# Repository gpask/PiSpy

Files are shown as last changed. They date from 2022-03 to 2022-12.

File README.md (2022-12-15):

# PiSpy: An Affordable, Accessible, and Flexible Imaging Platform for the Automated Observation of Organismal Biology and Behavior

<p align="center">
  
</p>

PiSpy has now been published at PLOS One! Check it out [here](https://journals.plos.org/plosone/article?id=10.1371/journal.pone.0276652)\!

This project is licensed under [GNU General Public License v3.0](https://github.com/gpask/PiSpy/blob/master/LICENSE)\
The hardware is licensed under [CERN-OHL-S v2](https://github.com/gpask/PiSpy/blob/master/Hardware/LICENSE)\

<br /><span xmlns:dct="http://purl.org/dc/terms/" property="dct:title">PiSpy</span> by <span xmlns:cc="http://creativecommons.org/ns#" property="cc:attributionName">Benjamin I. Morris, Marcy J. Kittredge, Bea Casey, Owen Meng, André Maia Chagas, Matt Lamparter, Thomas Thul, Gregory M. Pask</span> is licensed under a <a rel="license" href="http://creativecommons.org/licenses/by-sa/4.0/">Creative Commons Attribution-ShareAlike 4.0 International License</a>.<br /></a>

oshw_facts (1)

PiSpy OSHWA\
This project is Open Source Hardware Association certified [OSHWA UID US002095](https://certification.oshwa.org/us002095.html)

**Contents:**
* [Summary](#summary)
* [Overview of the PiSpy](#overview-of-the-pispy)
* [Video and time lapse image recording across various scales](#video-and-time-lapse-image-recording-across-various-scales)
* [Custom setup for monitoring ant behavior](#custom-setup-for-monitoring-ant-behavior)

## Summary
A great deal of understanding can be gleaned from direct observation of
organismal growth, development, and behavior. However, direct
observation can be time consuming and influence the organism through
unintentional stimuli. Additionally, video capturing equipment can often
be prohibitively expensive, difficult to modify to one's specific needs,
and may come with unnecessary features. Here, we describe the PiSpy, a
low-cost, automated video acquisition platform that uses a Raspberry Pi
computer and camera to record video or images at specified time
intervals or when externally triggered. All settings and controls, such
as programmable light cycling, are accessible to users with no
programming experience through an easy-to-use graphical user.
Importantly, the entire PiSpy system can be assembled for less than
\$100 using laser-cut and 3D-printed components. We demonstrate the
broad applications and flexibility of the PiSpy across a range of model
and non-model organisms. Designs, instructions, and code can be accessed
through an online repository, where a global community of PiSpy users
can also contribute their own unique customizations and help grow the
community of open-source research solutions.

## Overview of the PiSpy

<p align="center">
  
</p>
Shown above is the base model of the PiSpy for simple image or video
capture (Fig. 1a). A 3D printable holder mounts both the Raspberry Pi
and PiCamera to a laser cut wooden frame, allowing for easy height
adjustment (Fig. 1A-B). The stands on the frame are also reversible, and
a 3D-printed ball and socket mounts the PiCamera, allowing for free
rotation (Fig. 1C). Optionally, the Raspberry Pi computer can connect to
input and/or output components, such as a motion sensor or lighting,
respectively. This entire setup can be assembled for less than \$100, or
cheaper if multiple setups are being bought at once or certain features
are omitted (see Bill of Materials in GitHub. A complete user's guide
and assembly manual can be found in the Supplementary Materials of the
published paper and will also be continually updated on the GitHub
repository (https://github.com/gpask/PiSpy). The GUI for the PiSpy,
written in Python3 using the TKinter package, controls the functionality
of the PiSpy. Features include capture mode, timed or input-triggered
capture, light control, and camera resolution (Fig. 1D). For more
advanced controls, such as changing the default image/video name and
storage location or the specific camera settings, instructions are
written in the user's manual for how to edit these in the code itself.

## Video and time lapse image recording across various scales

Imaging of 10 *D. melanogaster* larval locomotion on an agar plate
provided sufficient resolution for analysis with the ImageJ image
processing software, as shown in the above video (sped up to 5x speed):
<p align="center">
  Fig. 2a
</p>

Video of crayfish behavior when placed in an aquarium allowed for the
observation of subtle movements of the swimmerets and legs, even though
the animals were underwater and being viewed through a plastic
container:
<p align="center">
  Fig. 2b
</p>

Automated image capture also makes the PiSpy an effective device for
capturing and visualizing organismal growth over time. Time-lapse
imaging every 5 minutes (and converted to a video at 225 fps) of various beans (*Phaseolus vulgaris*) growing in clear
planters showed detailed root and shoot growth:
<p align="center">
  Fig. 2c
</p>

At a smaller scale, imaging every 5 minutes (and converted to a video at 90 fps of the soil bacterium *Bacillus mycoides*
captured the growth and expansion process over time:
<p align="center">
  Fig. 2c
</p>

## Custom setup for monitoring ant behavior

<p align="center">
  Fig. 3a
</p>

The flexibility of the PiSpy allows it to be customized for more
specific research purposes, as shown above. For example, we have used the PiSpy to
monitor the social behaviors in colonies of the Indian jumping ant,
*Harpegnathos saltator*. Because the ants are housed in nestboxes of a
fixed size, we have modified the wooden frame and mount to enclose the
container to allow for easy overhead recording of the colony, as shown in the image above.
To maintain a light-dark cycle for the ants, we used the LED light
control capabilities of the PiSpy to be able to record social behaviors
throughout the day. Custom LED printed circuit boards (PCBs) can be
connected to the general-purpose input output (GPIO) pin of the
Raspberry Pi and allow for the cycling of white and red lighting.

The sample videos below show the ability of the PiSpy to record animal behavior
in both day and night, with sufficient resolution to capture specific behaviors 
such as antennal dueling (asseen in the daytime recording).
In our experiment, the red light is not detected by the ants but allows
for both day and night imaging. Specific camera settings are used to
record in each different lighting conditions to ensure the desirable
imaging quality. We have programmed in default camera settings for day
and night recording, but the user's manual provides instructions for how
to modify these within the PiSpy code.
<p align="center">
  Fig. 3b
</p>
<p align="center">
  Fig. 3c
</p>

The GPIO pins of the Raspberry Pi can also be used to trigger image or
video capture with an external sensor, such as a motion sensor or IR
break beam. In our setup (below), an ant disrupts the IR beam as it walks to a
foraging arena, and again when it returns to the main colony. The physical setup is 
shown in the image below, including the LEGO contraption to holding the break beam (right side):
<p align="center">
  Fig. 3b
</p>

A sample video in which ants return to the main colony carrying crickets is shown below:
<p align="center">
  Fig. 3c
</p>

As an alternative to automated recordings at fixed time intervals, triggered recordings such as these
could be used to monitor specific activities, such as feeding patterns
or other behaviors. It is our hope that users will create their own
modifications of the PiSpy hardware and/or software and will share these
for use by other researchers and inspire further customizations,
allowing it to serve as both a general use tool and one that can be
applied to highly specific experimental approaches.

Contributors to PiSpy:
Benjamin I. Morris, Marcy J. Kittredge, Bea Casey, Owen Meng, André Maia Chagas, Matt Lamparter, Thomas Thul, Gregory M. Pask

For this README, all videos were converted to GIF using ezgif.com

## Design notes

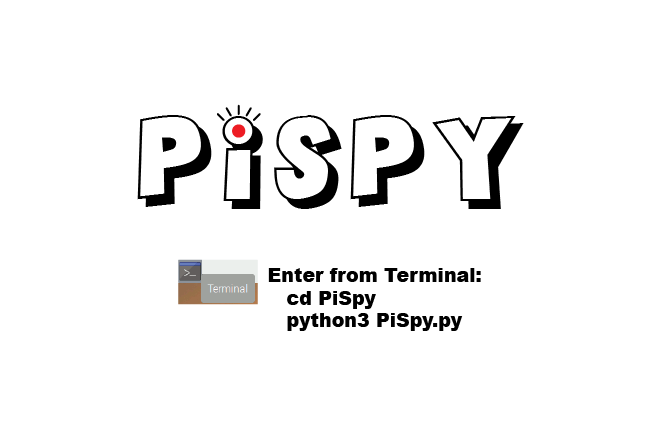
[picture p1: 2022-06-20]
PiSpy desktop.png

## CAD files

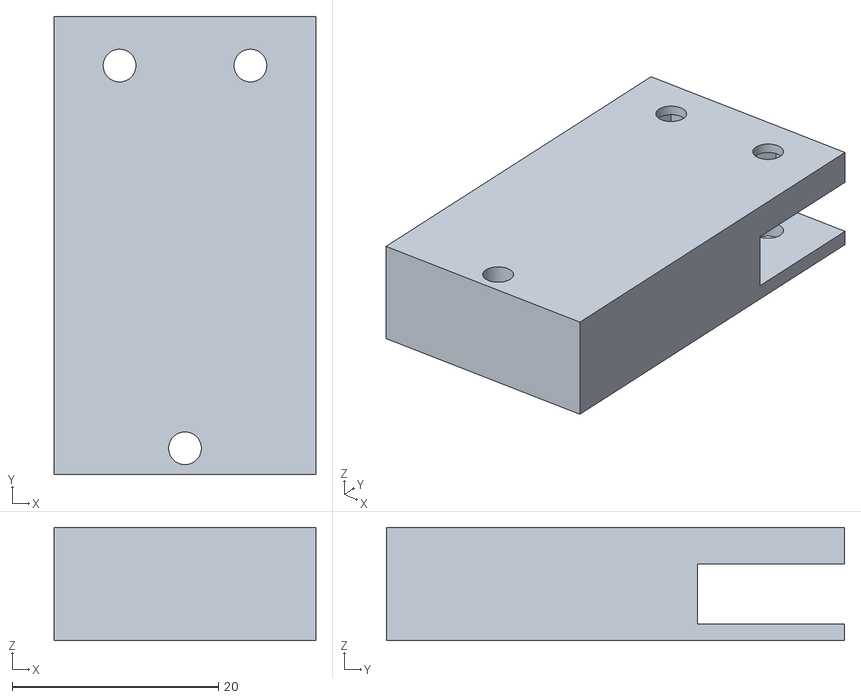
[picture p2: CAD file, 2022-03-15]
Hardware/LED light setup/3D printing/slider mounting bracket.STL
25.4 x 44.4 x 11.0

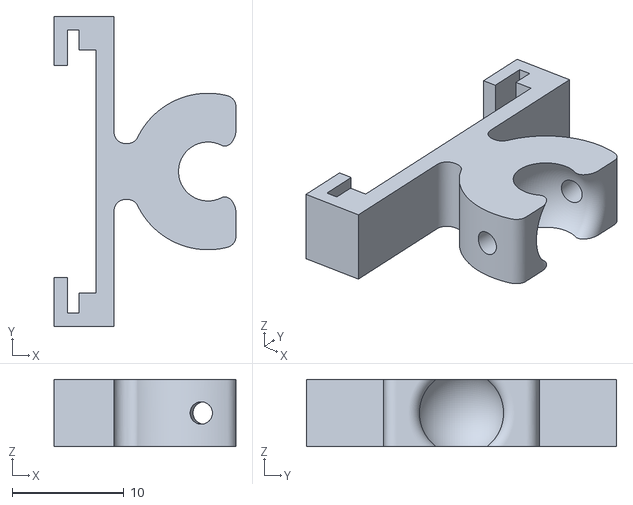
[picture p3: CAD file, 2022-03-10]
Hardware/Original PiSpy/Camera mount.stl
16.3 x 27.7 x 6.00

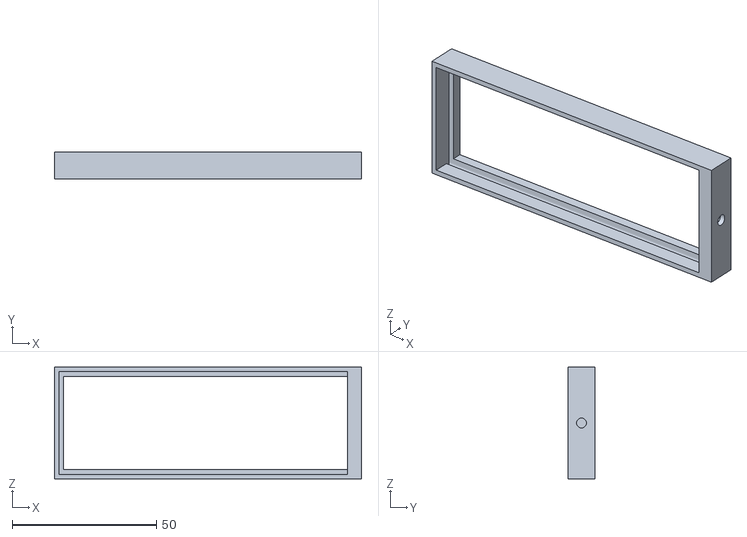
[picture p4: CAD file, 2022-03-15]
Hardware/LED light setup/3D printing/light slider.STL
106.4 x 9.53 x 38.7

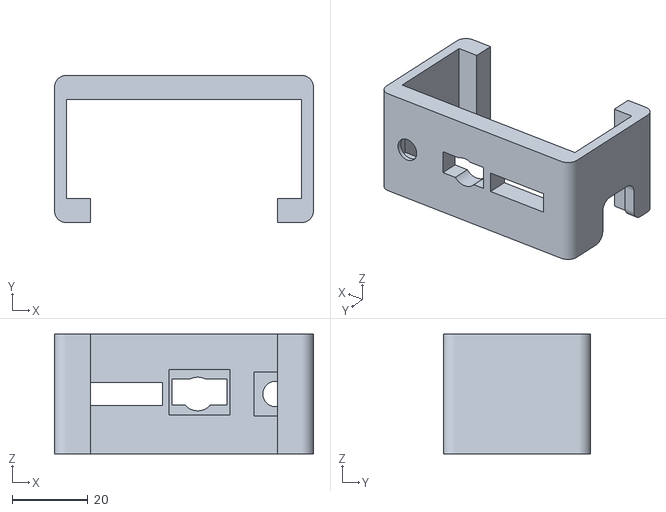
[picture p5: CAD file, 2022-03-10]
Hardware/Original PiSpy/RPi mount.STL
68.6 x 39.0 x 31.8

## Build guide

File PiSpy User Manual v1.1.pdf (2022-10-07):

PiSpy User’s Manual | 1

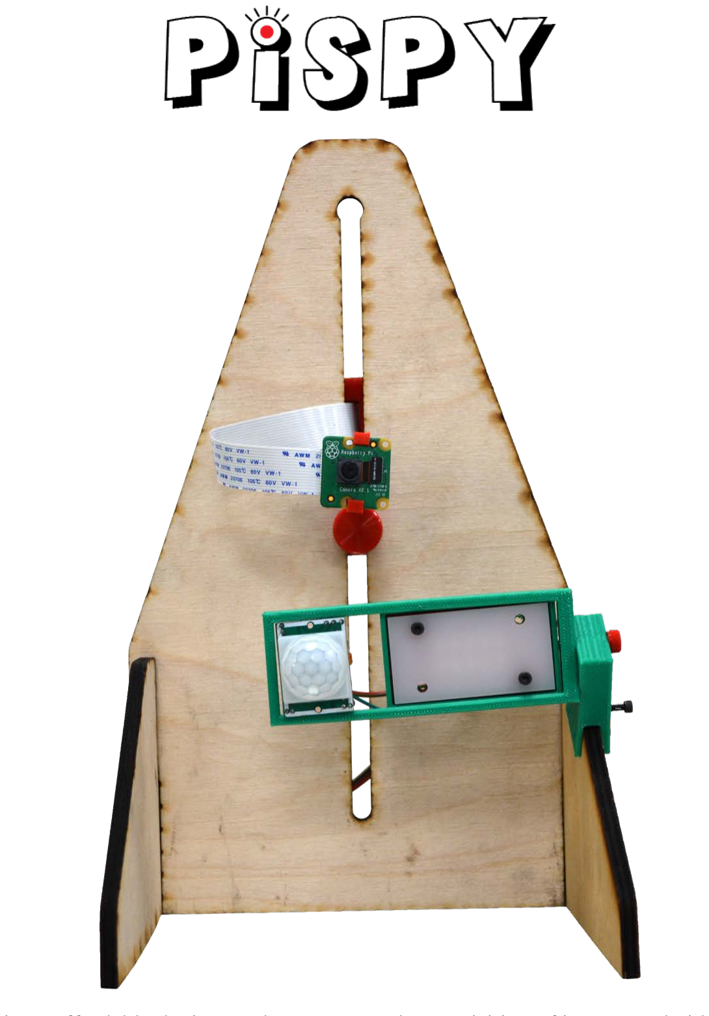
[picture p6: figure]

The PiSpy is an affordable device used to automate the acquisition of images and videos. It was shared on bioRxiv in 2022 (https://www.biorxiv.org/content/10.1101/2022.03.21.485129v1). It uses a Raspberry Pi computer and camera to record video and images at specified time intervals or when triggered by an input signal, such as a motion sensor or force plate. Additionally, it can automate the control of LED lights. All settings for the PiSpy are controlled through a graphical user interface that uses the TKinter Python package. The following user guide will outline how to set up and operate the PiSpy. Our testing was with a Raspberry Pi3b or Pi4, which is primarily what this guide is written for, but with some modifications the PiSpy can also be used with older Raspberry Pi models.

### Table of Contents

PiSpy Hardware Assembly

Fabrication of Components

The hardware files associated with PiSpy can be downloaded from the GitHub repository (https://github.com/gpask/PiSpy/tree/master/Hardware/Original%20PiSpy).

The wooden stand used to mount PiSpy can be laser cut from 3/8 inch plywood using the .svg file. The 3D-printed components were printed with polylactic acid (PLA) using the .stl files.

Assembly Instructions

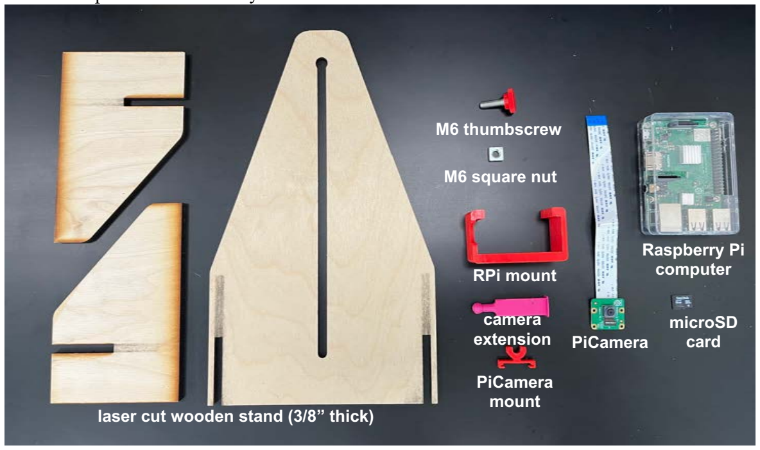
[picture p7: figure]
laser cut wooden stand (3/8” thick); PiCamera mount; camera extension; RPi mount; M6 square nut; M6 thumbscrew; PiCamera; microSD card; Raspberry Pi computer

All the components for assembly are shown below:

First, assemble the wooden stand by sliding each support into the taller mount like so:

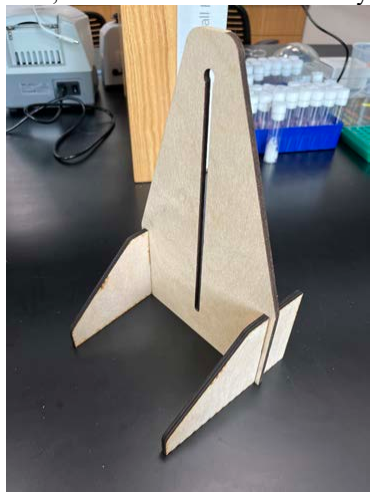
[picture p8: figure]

Next, detach the ribbon cable from the PiCamera and insert one end into the Raspberry Pi’s camera port.

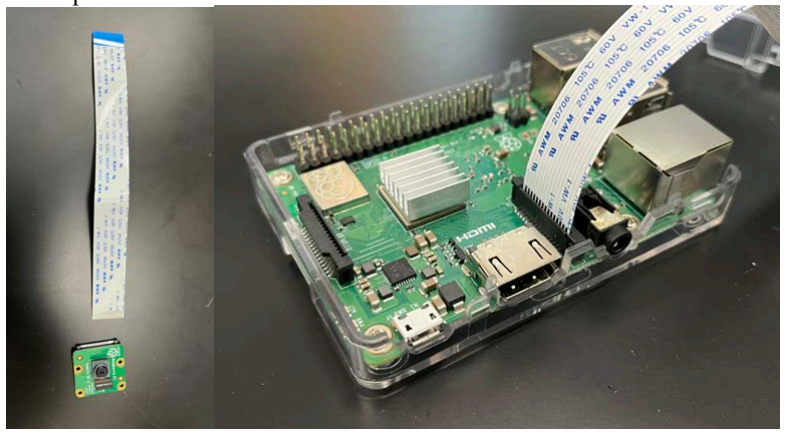
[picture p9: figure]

Then insert the PiCamera into the PiCamera mount (be sure not to block the ribbon cable connector).

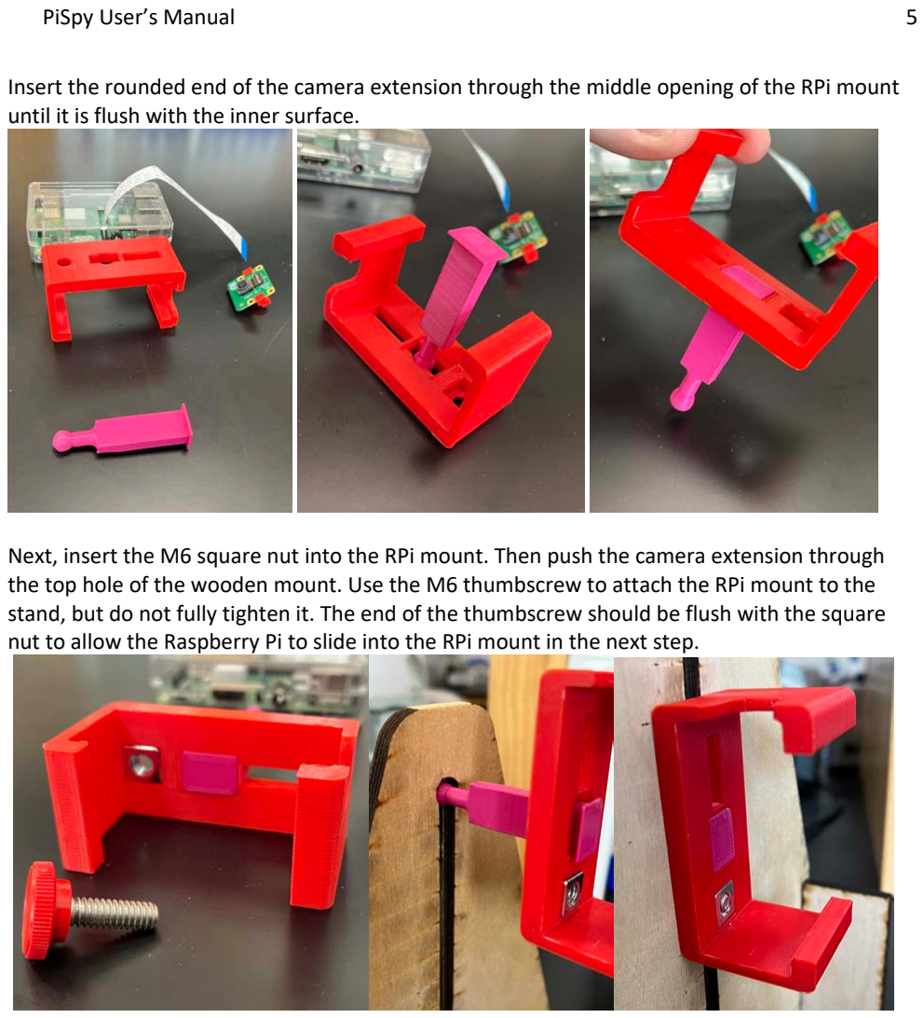
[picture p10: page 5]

Insert the rounded end of the camera extension through the middle opening of the RPi mount until it is flush with the inner surface.

Next, insert the M6 square nut into the RPi mount. Then push the camera extension through the top hole of the wooden mount. Use the M6 thumbscrew to attach the RPi mount to the stand, but do not fully tighten it. The end of the thumbscrew should be flush with the square nut to allow the Raspberry Pi to slide into the RPi mount in the next step.

First insert the camera ribbon cable through the top rectangular opening in the RPi mount. Then slide the Raspberry Pi and case into the RPi mount. (Note: If your specific case does not fit inside RPi mount, you can adjust the scale of that specific axis before 3D printing.)

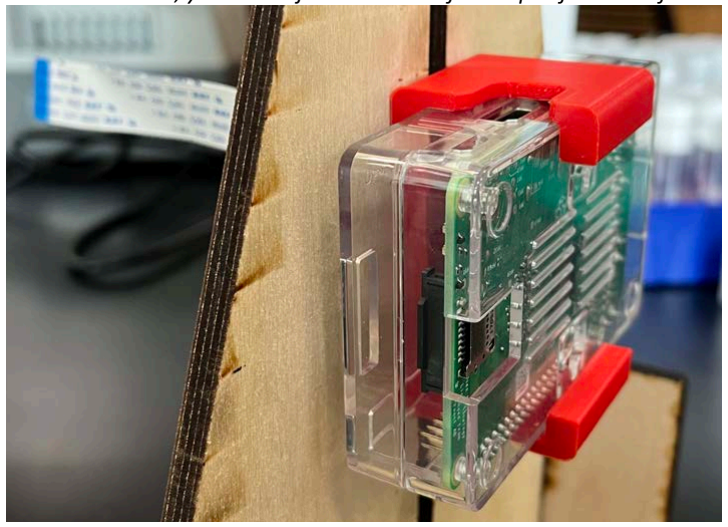
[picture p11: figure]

Attach the PiCamera and mount to the “ball” end of the camera extension and connect the ribbon cable.

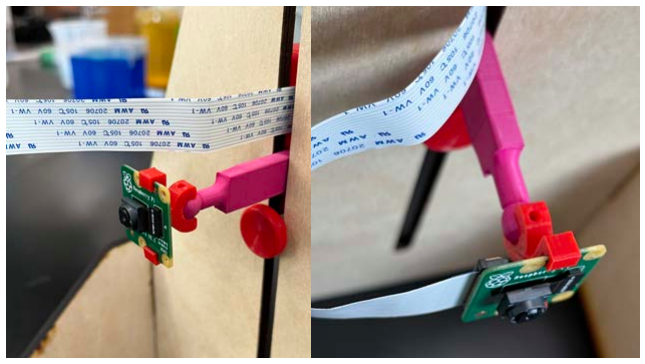
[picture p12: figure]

Connect the power supply, HDMI cable, keyboard, and mouse. The microSD card will be used in the next section to load the PiSpy disk image and will be inserted as shown below:

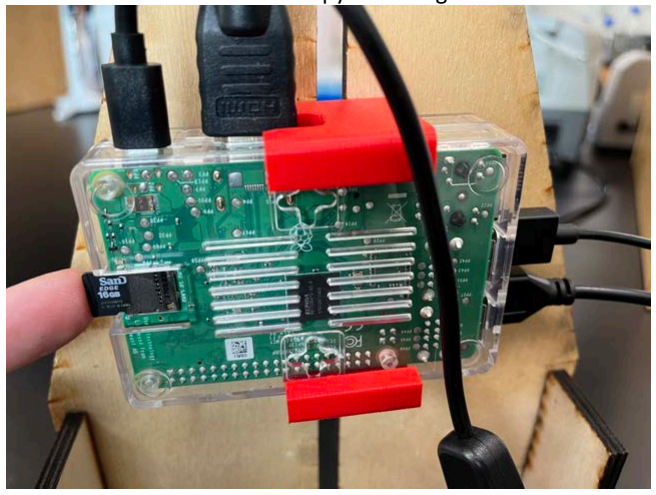
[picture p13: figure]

Setting up the Raspberry Pi Computer
Installing Raspberry Pi OS
The first step to running PiSpy is to set up the Raspberry Pi OS operating system on the computer. To do so, on a computer with micro SD card reader, download the Raspberry Pi imager (https://www.raspberrypi.com/software/) and the PiSpy disk image from the GitHub repository (https://github.com/gpask/PiSpy/blob/master/Software/PiSpy%20disk%20image.md). Insert the micro SD card into the computer and open the imager.

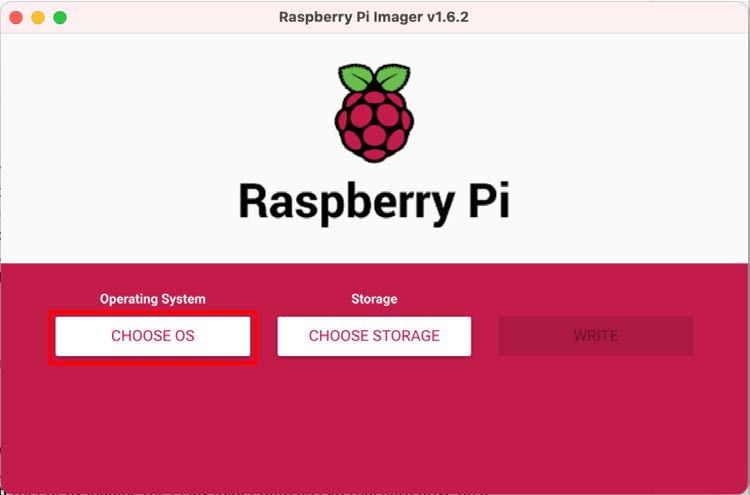
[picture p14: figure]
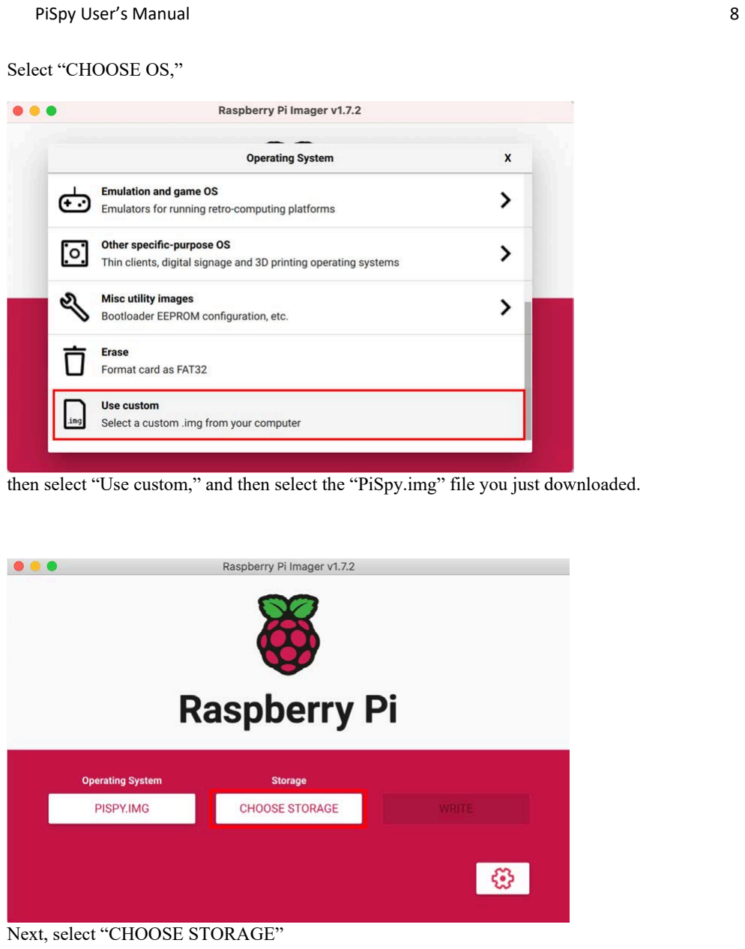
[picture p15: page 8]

Select “CHOOSE OS,”

then select “Use custom,” and then select the “PiSpy.img” file you just downloaded.

Next, select “CHOOSE STORAGE”

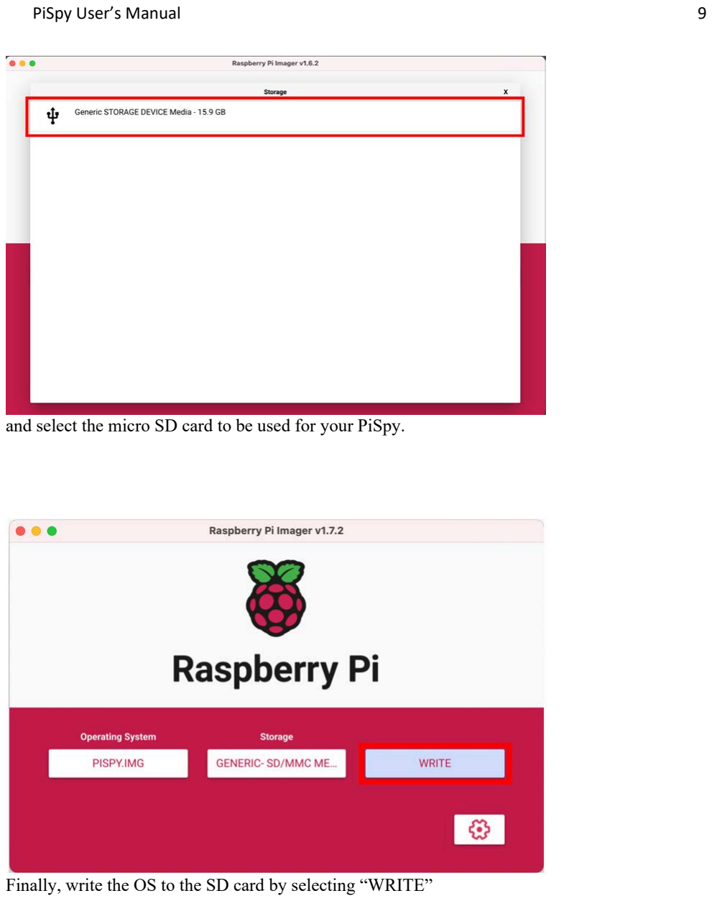
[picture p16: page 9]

and select the micro SD card to be used for your PiSpy.

Finally, write the OS to the SD card by selecting “WRITE”

and confirming that this will erase any previous data on the SD card.

When complete, insert the micro SD card into the Raspberry Pi (as shown on page 7) and power it on. Once booted, your desktop should look like this:

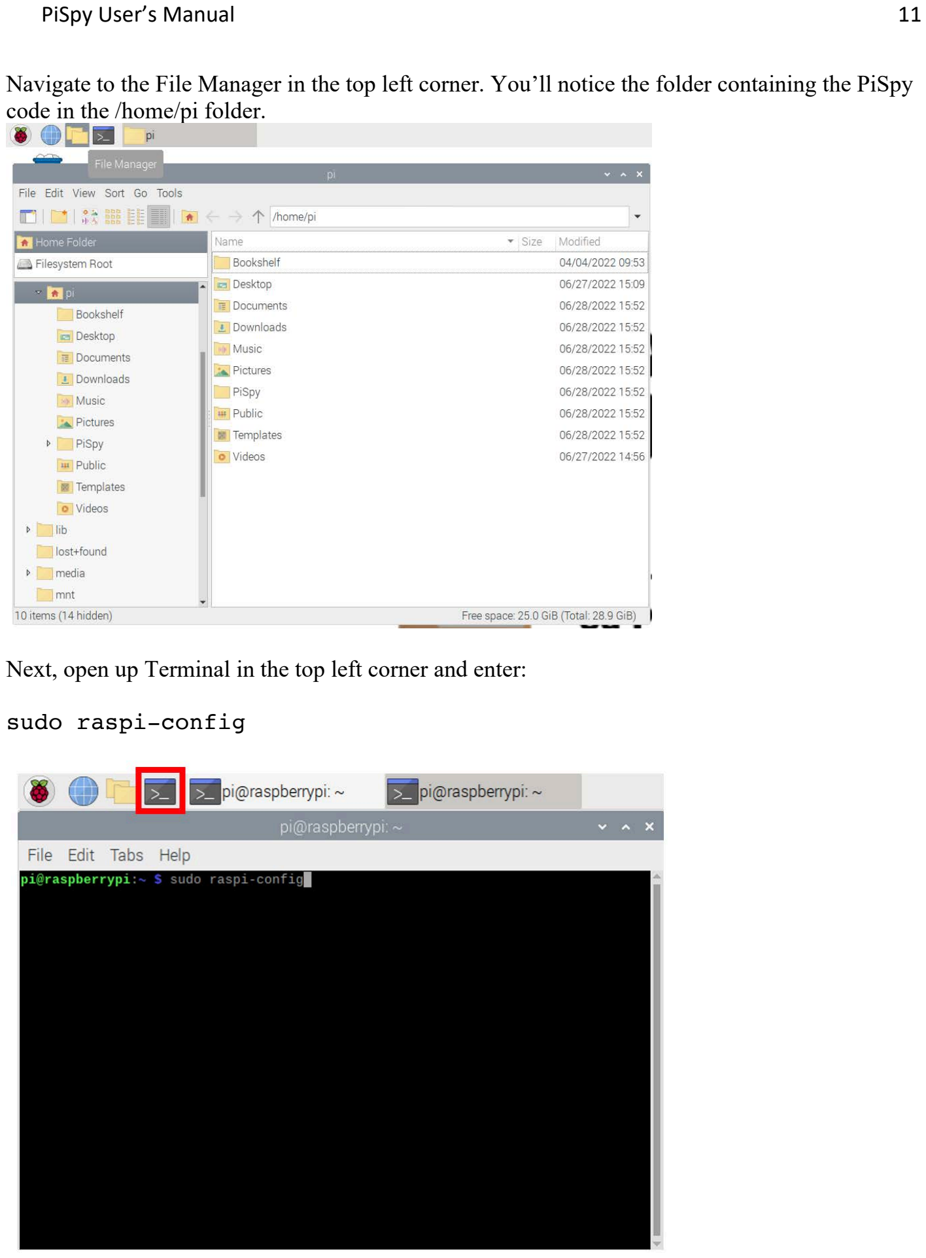
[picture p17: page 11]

Navigate to the File Manager in the top left corner. You’ll notice the folder containing the PiSpy code in the /home/pi folder.

Next, open up Terminal in the top left corner and enter:

sudo raspi-config

This will open the following menu. Navigate toward “6 Advanced Options” and press the enter key. Then select “A1 Expand Filesystem” and press enter again. This will expand the accessible filesystem to the size of your micro SD card.

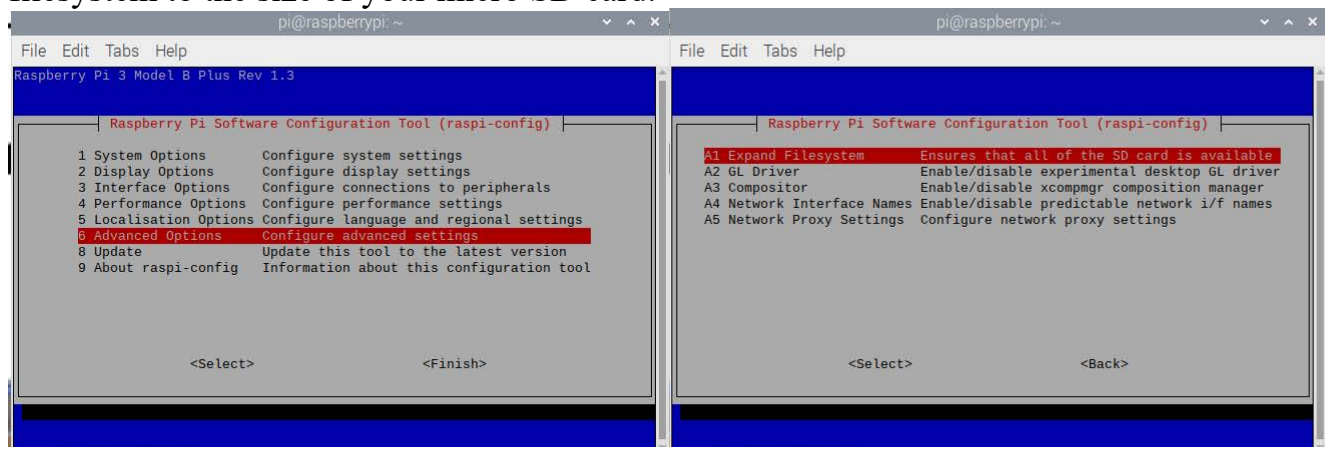
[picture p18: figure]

Navigate to “Finish” by pressing the right arrow button, and then select yes to reboot and start filesystem expansion.

Operating the graphical user interface
To access the GUI, open the command line by clicking on the terminal icon on the top bar of the screen. Then, enter the following commands, first to move to the PiSpy folder and then to open the PiSpy Control window, which is where the PiSpy is operated from:

cd PiSpy
python3 PiSpy.py

If you have already entered those commands, you can use the up arrow to access previously used commands in terminal. Also note that the cd PiSpy will only work if the folder containing the PiSpy code is still named “PiSpy.” If the name is changed for some reason (as can happen when unzipping the file), either change the name back to PiSpy or enter the new name for the folder when typing that command.

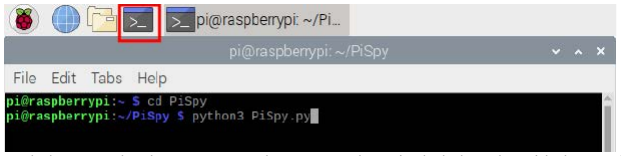
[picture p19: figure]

To help remember how to access the GUI, we have included on the Github repository a suggested background for the PiSpy (“PiSpy desktop.png”) and included it in the disk image.

Once the GUI is opened, choose your desired capture mode (image or video) and frequency (timed or triggered) by checking the corresponding boxes. Only one mode and frequency combination (i.e. timed videos) should be selected at a time. Additionally, select the camera resolution by checking the box of the desired resolution, and, for video recording, specify the frame rate. If no resolution is selected, the PiSpy will by default record with a resolution of 1920 x 1080. This link (https://picamera.readthedocs.io/en/release-1.12/fov.html#camera-modes) lists the possible resolutions and framerates for the V1 and V2 PiCameras. Depending on the videos being recorded and the quality of the microSD card used, selecting frame rate/resolution combinations at the upper limits of the accepted range can result in skipped frames. If this occurs, lower either the resolution or the frame rate.

Timed recording:
Timed recording can be used when the user wants images or videos to be recorded at fixed intervals. The image or video frequency should be input in the hh:mm format (using a 24 hour clock), and specifies how often images/videos are recorded. For instance, in the below image, 30 second videos with a frame rate of 20 fps and a resolution of 1920x1080 will be recorded every 1.5 hours for 3 days. Note that the frequency must be less than 24 hours.

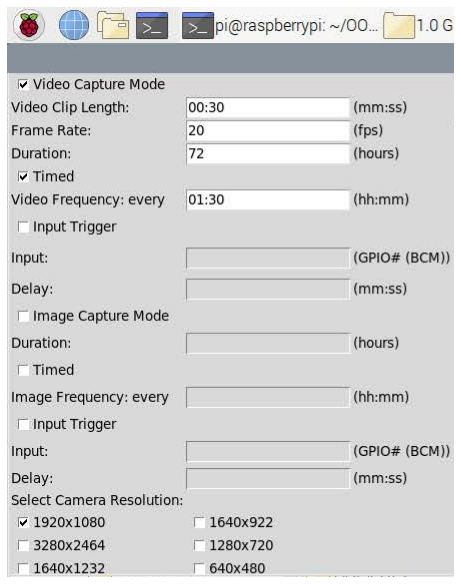
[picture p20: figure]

Input trigger
Input trigger mode can be used when the user wants an external source such as a motion sensor or force plate to determine when images or videos are recorded. See Connecting GPIO sensors for input trigger for more information on how to use different sensors for input trigger mode.

Light Control
If light control is desired, check the corresponding box and enter the times when each light should be turned on/off (hh:mm format, using a 24-hour clock). Using the red and/or white light buttons, turn on the light(s) you want on when the program starts running. In the image below, the white lights will be on from 7 AM to 7 PM, and the red lights will be on from 7 PM to 7 AM.

Note on Red Lights at Night
The default settings programmed into the PiSpy are what we found in testing to give the best quality night images/recordings. However, because of the PiCamera’s auto white balance settings, if the subject isn’t getting enough light or is sending back too much glare towards the camera, images/videos recorded at night can appear washed out. In addition to making changes to the PiSpy settings (see Adjusting Default PiSpy Settings below), changing the location and angle of the lights on the PiSpy, the proximity of the subject to the lens, and the height of the camera can all also help with improving night image quality.,

Quick Capture
If the user wants to manually take a picture or video, they can use the quick capture button. Select either video capture mode or image capture mode, and if taking a video also specify the clip length. Then, click the quick capture button to record.

Preview
To preview the output of the camera, the user can select the “preview’’ button. The preview length box allows the user to select how long the preview will last for (while the preview window is open, the user cannot interact with the PiSpy Control window). If no time is selected, the PiSpy will default to a 10 second preview.

File Identifier
Optionally, a file identifier can be entered to distinguish between different experiments and/or PiSpy devices. The input in this box will be placed before the default title (local timestamp), but an input here is not required.

Running the PiSpy Program
Once all the settings have been chosen, click the apply button to run the program.
Once the settings are applied, the PiSpy control window will close to run the program, and the chosen settings will be printed out to the terminal window. If the program needs to be stopped before the designated end time, perform a keyboard interrupt in terminal (Control + C) or close the terminal window by clicking the X in the top right corner of the window. This will keep any previously recorded images/videos, but stop the program from recording any more, allowing the user to relaunch the control window and select new settings if desired.

Connecting GPIO sensors for input trigger
Connecting a PIR motion sensor
A PIR motion sensor will have three pins: VCC, GND, and OUT. On some PIR motion sensors, the labels are under the cap; if this is the case, gently remove the cap to be able to identify the pins (the image below is a PIR sensor with the cap removed to show the pin labels). Using the image below as a reference (or by using the “pinout” command in terminal), connect the VCC pin to a 5V or 3.3V power supply pin on the Raspberry Pi, the GND pin to a ground pin on the Pi, and the OUT pin to any of the numbered GPIO pins on the Pi. GPIO board numbering differs between different models of the Raspberry Pi, so if you are not using the Raspberry Pi 3 you will need to consult a different chart when connecting the sensor. The OUT will output a voltage when the sensor is activated, which will be received by the Raspberry Pi and trigger the PiSpy to record an image/video (depending on selected settings). The diagram below is just a suggestion and does not need to be followed exactly; the sensor will work as long as GND is plugged into a ground pin, OUT to a GPIO pin, and VCC to a power supply.

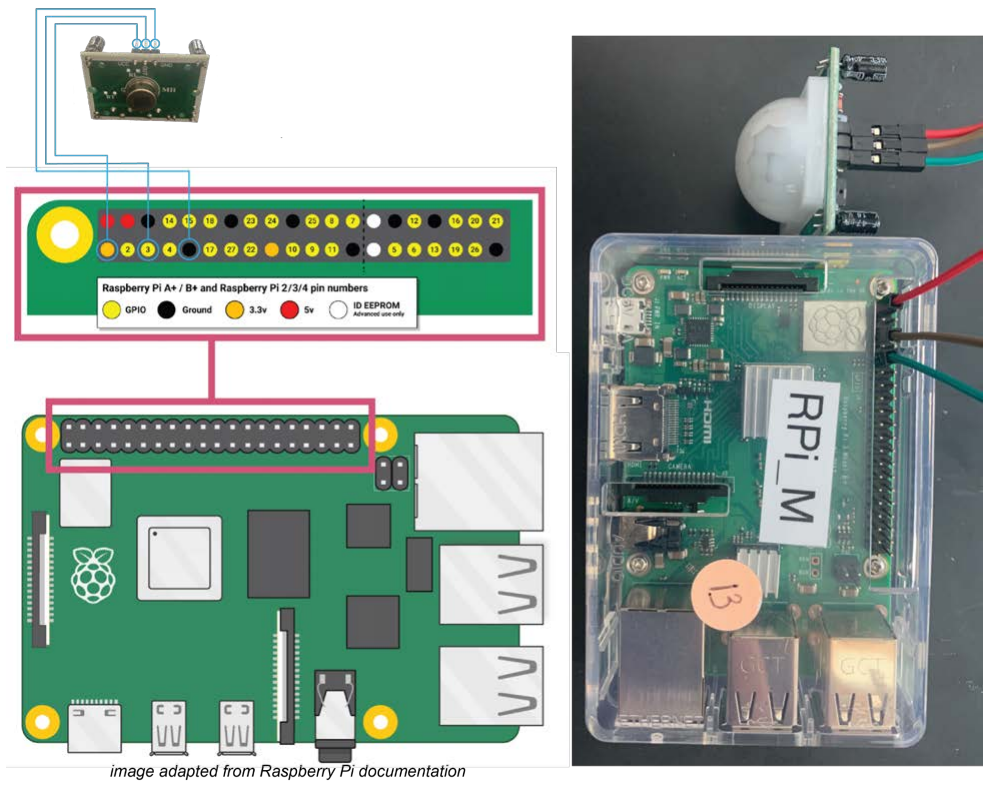
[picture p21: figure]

Connecting an IR break beam
An IR break beam has two components, an emitter and a receiver, but the wiring is similar to a motion sensor. The emitter emits a beam of IR light and has two wires, a red one that receives power from a 5V or 3.3V (the range will be better if using 5V) power supply on the Raspberry Pi, and a black one that connects to a ground pin. The receiver, which receives the signal from the emitter, has the same red and black wires which must be plugged into a different power and ground pin, but also has a white or yellow output wire that should be plugged into one of the general purpose GPIO pins. See the image below for reference. As noted above, the power can come from a 3.3V pin, but the range of the break beam will be smaller. Additionally, any GPIO pin can be used, not just 2 (just make sure to specify which one the input is plugged into when you run the PiSpy)

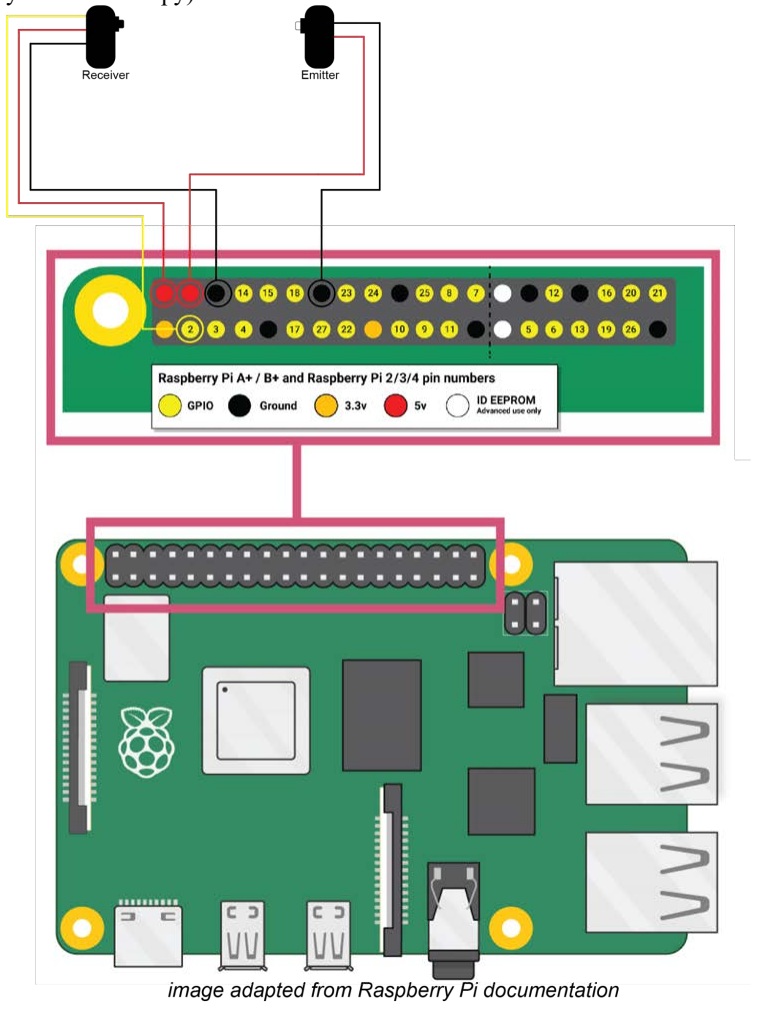
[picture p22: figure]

Note on PIR motion sensors
In our testing, several commercially available and inexpensive PIR motion simply do not function. If the motion sensor does not correctly trigger image/video acquisition, double check that every connection is in the proper position and secure, and if that doesn’t work, consider trying a different sensor.

Note on IR break beams
An IR break beam has two parts, an emitter that sends out IR light and a sensor that receives that signal and will signal to the computer when that beam is broken. In our testing, small objects (we were using ants) don’t always reliably break the beam and trigger the sensor. To make the sensor sensitive enough to trigger when an ant passed it, we used LEGOs® to decrease the total area that the sensor could receive IR signal from, and placed a single index card in front of the sensor as well. The index card is partially transparent to IR light, so when nothing else was between the sensor and the emitter the beam was not broken, but when an ant passed it would trigger video acquisition. Our suggestion is to test break beam sensitivity with your desired subject before running any experiment to confirm that the beam will trigger, and if it does not increase the sensitivity, which can be done with DIY tools and further testing as we did.

Note on BOARD vs BCM GPIO labeling
There are two different ways Raspberry Pi GPIO pins can be referred to. BOARD labeling refers to the actual position of the pin on the GPIO board, whereas BCM (Broadcom chip-specific pin numbers) refers to the lower-level functions of the pins. The PiSpy uses the BCM labelling throughout its code, so this is how the input source must be referred to when using input trigger mode.

Note on code for input triggers
Different input triggers function in slightly different ways, and the code (in the “Input_Trigger.py” file) must be slightly different for each of them. As currently deposited on GitHub, the code is written to work with an IR break beam, which has an output of 1 when the beam is not broken and 0 when the beam is broken. As advised in the Input_Trigger.py code, if using a PIR motion sensor, which outputs a 0 when it does not sense motion and a 1 when it does, change lines 56 and 113 of the Input_Trigger.py document from “if x == 0:” to “if i >= 1:” and comment out (place # signs before) lines 50-54 and 108-112. See the screenshots below for reference.

While we do not provide code/instructions for wiring of other types of input triggers besides PIR motion sensors and IR break beams, there are a considerable number of online resources available to help with any other types of sensor, many of which can be found directly on websites like Adafruit and raspberrypi.com when purchasing the sensors.

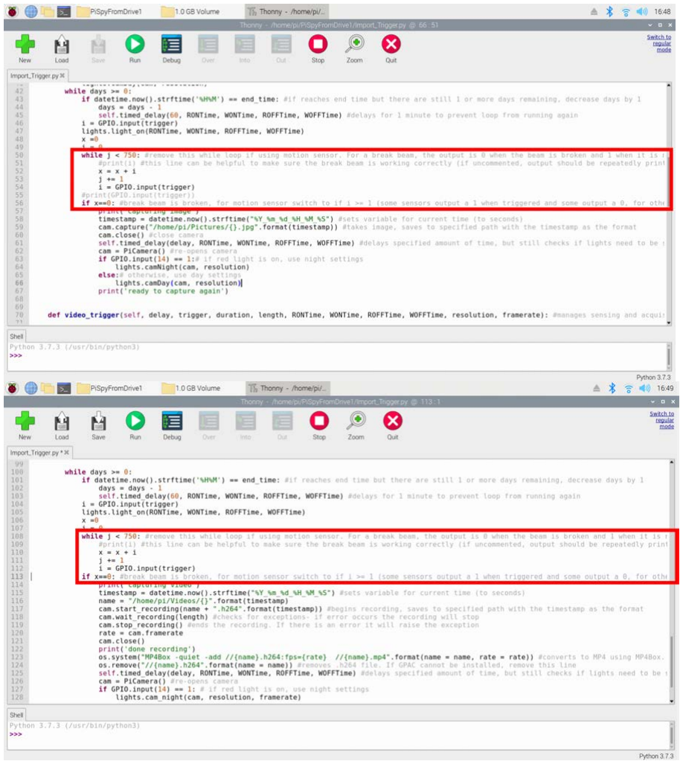
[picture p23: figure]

Using input trigger mode
In the PiSpy control window, specify which GPIO pin the trigger source is connected to, using the BCM format (the white text in the above diagram). Additionally, specify in the mm:ss format how long a delay is desired between image or video captures. Note that many sensors (i.e. PIR motion sensors) also have a mechanically adjusted delay setting, so this can also be adjusted to set the device’s delay. The PiSpy will use whichever delay is longer. In the image below, 1640x1232 images will be recorded when triggered by a sensor plugged into GPIO 4 with a 15 second delay. Recording will occur for 6 hours.

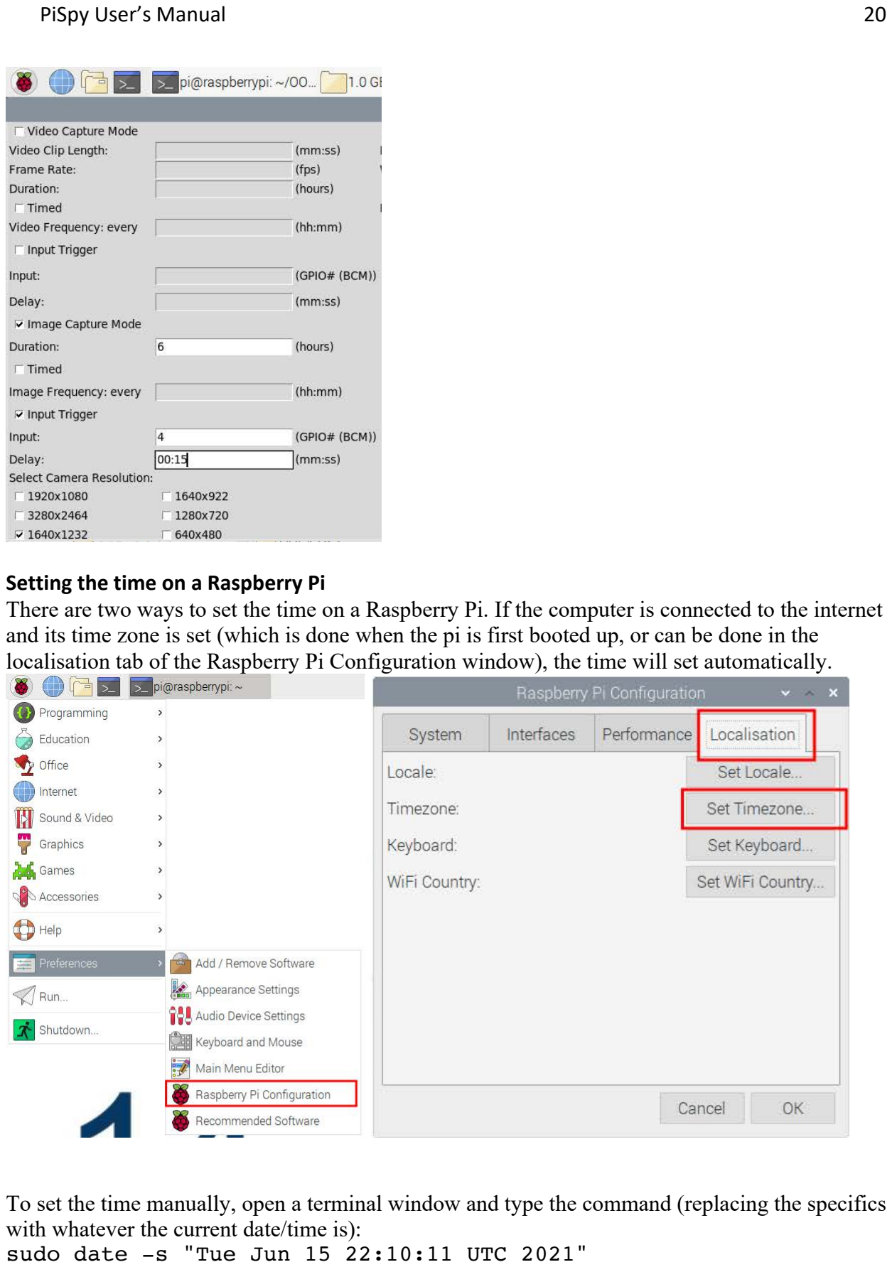
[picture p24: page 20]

Setting the time on a Raspberry Pi
There are two ways to set the time on a Raspberry Pi. If the computer is connected to the internet and its time zone is set (which is done when the pi is first booted up, or can be done in the localisation tab of the Raspberry Pi Configuration window), the time will set automatically.

To set the time manually, open a terminal window and type the command (replacing the specifics with whatever the current date/time is):
sudo date -s "Tue Jun 15 22:10:11 UTC 2021"

Optional: connecting a Real-Time Clock (RTC) to the PiSpy
If, for connectivity, security, or other reasons it will not be possible to connect your PiSpy to the internet, a physical RTC can be connected to the GPIO pins to maintain accurate timing on the device. There are several different RTC options available that we have tested and confirmed to work with the PiSpy, but note that some of these use the same GPIO pins that other optional PiSpy add-ons (such as lights or motion sensors) require. Adafruit has a thorough and easy-to-follow tutorial for connecting different RTCs to a Raspberry Pi, and is also a good source to purchase these devices if they are required for your project: https://learn.adafruit.com/adding-a-real-time-clock-to-raspberry-pi.

Adjusting Default PiSpy Settings
By default, the PiSpy camera will have an ISO of 200 during day recording (no lights on or white lights on), and an ISO of 800 during night recording (red lights on). At night, brightness (set to 43 on a scale from 1 to 100) and contrast (set to -8 on a scale from -100 to 100) are also lowered, as this helped improve image quality with the red LED lights on. If the user wants to adjust any of these settings, open the Day_Night_Mode.py file in the PiSpy folder. Then, make the desired adjustments under the camDay function (to change day settings) or the camNight function (to change night settings). Note that there are two camDay and two camNight functions (one for when framerate is specified and one for when it is not. To ensure a change in settings will always be implemented, make sure to adjust settings in both of these functions. In the screenshot below, the functions highlighted in red control day settings, and the ones in blue control night settings. Note, however, that image quality, especially at night, is also effected by the physical setup of the Pi. See Note on Red Lights at Night above for slightly more detail on this.

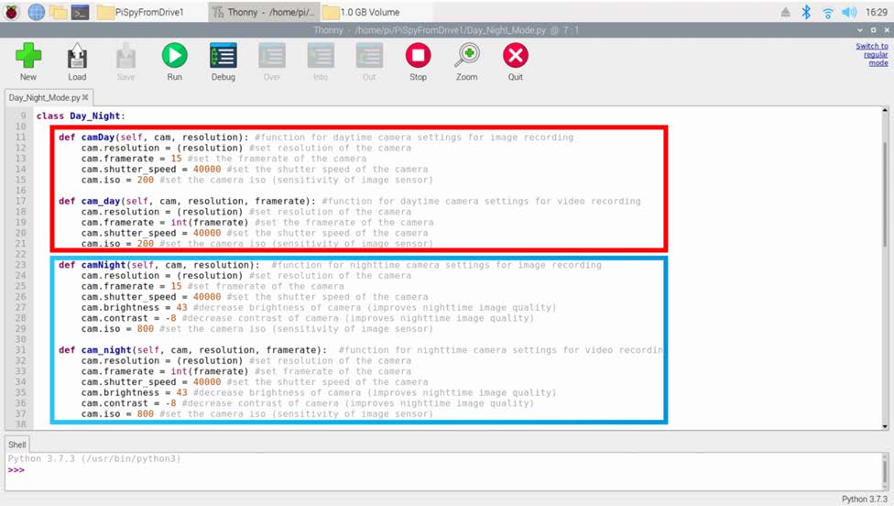
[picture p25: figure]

By default, the PiSpy will title images and videos with the time they were recorded (in the format year_month_day_hour:minute), and will store them to the default Pictures folder (/home/pi/Pictures).
To change either of these settings for image recording, open the “Image.py” file. To change the location the images are stored at, replace /home/pi/Pictures in line 20 with the path to the desired folder (make sure to leave the /{}.jpg after the path, as that is what specifies the file name). To change the file name, add any desired text before or after the {} in line 20 (the {} is a placeholder that tells Python where to put the timestamp in the filename). The format of the timestamp itself can be adjusted in line 18.

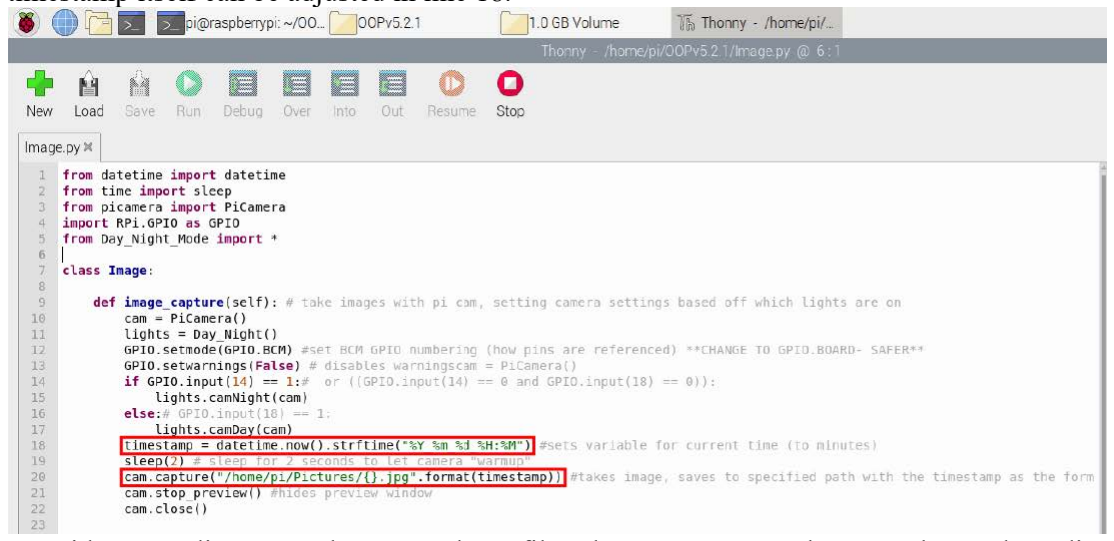
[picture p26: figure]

For video recording, open the “Record.py” file. The same steps as above can be used to adjust the file’s name and location, except the location/name is determined in line 24, and the format of the timestamp is determined in line 20.

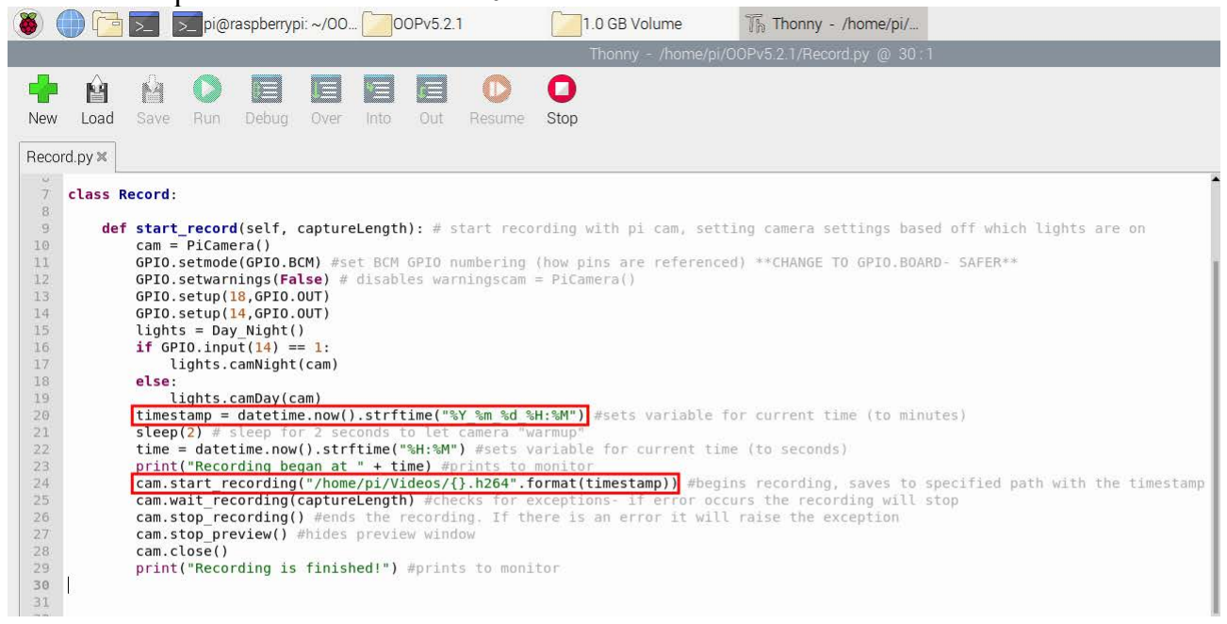
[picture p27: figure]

By default, PiSpy uses the a bitrate of 6000000 (6 mb per second), as we found in our testing that this provided sufficient video quality while keeping file sizes small and minimizing frame skipping in the videos. To change this to a different value, update the value specified in line 44 of “Record.py.”

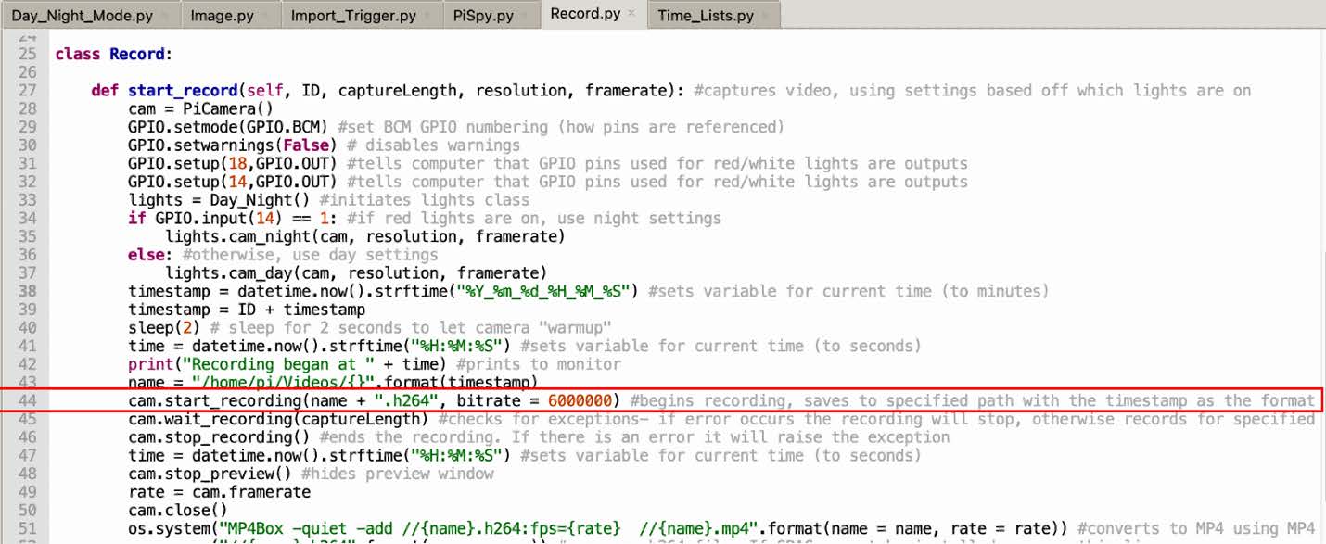
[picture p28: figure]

LED PCB Lighting
Designs for white/red LED Printed Circuit Boards (PCBs) are on the PiSpy GitHub repository and can be used to purchase PCBs from fabrication businesses. One or more LED PCBs must be connected to the GPIO board on the Raspberry Pi for lighting control. When the Pi is off, connect the GPIO pins to the corresponding pins on the LED PCB(s) as shown in the diagram below. For GPIO positions, please refer to the pinout diagram above. Alternatively, the pinout command in terminal will display a diagram of the GPIO for your Raspberry Pi model.

If using other lighting outputs, please note the GPIO pins of interest and that the GUI code may need to be modified.

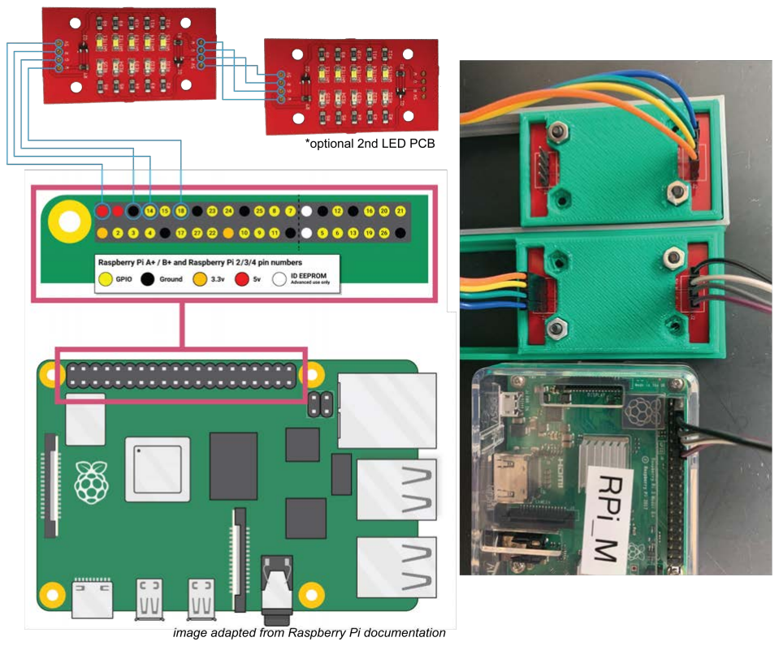
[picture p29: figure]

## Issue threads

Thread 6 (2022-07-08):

Error I/O

akshitasax, 2022-07-08:
Hello,

I was recording a 12-hour video overnight using PiSpy, and when I checked on it in the morning, the video had not been saved anywhere and this was what the command line interface looked like (screenshot 1). I have used this raspberry pi computer and PiSpy user to record 12-hour videos before, so I don't understand what could have changed. What could this error be due to?
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
Screenshot 1

Another raspberry pi computer with PiSpy on it that I have been using to record 12-hour videos also showed a similar error when I tried to record a 12 hour video (screenshot 2). The video did save as an mp4, but it was unseekable, and could not be opened by the data extraction software I use post-recording. This error has never happened on this computer before.
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
Screenshot 2

Is there anything I could do to fix this?

Thank you,
Akshita

gpask, 2022-07-19:
Hi Akshita,

I spent the last week running the same settings that you were using and didn't encounter that error message or the issue with data being saved. We're a little at a loss too because we never saw that error in any of our testing as well, just like you haven't seen it on your other PiSpy devices.

Do you have any GPIO devices connected (seems like LED board based on your settings)? It could be a failed connection of some sort based on the "I/O" of the error message.

My best advice would be to reimage the RPi, which you can now easily do using a PiSpy disk image we just uploaded to GitHub. You can find updated instructions for this more streamlined installation in the user's guide. Please let us know if you still see the error in the future, and good luck!

Greg

akshitasax, 2022-08-17:
Hi Greg,

Thank you for responding! We ended up reimaging the Rpi using SD cards with larger storage and that seemed to do the trick. Have not run into the same issue again since.

Thanks again,
Akshita

Closed 2022-08-22.

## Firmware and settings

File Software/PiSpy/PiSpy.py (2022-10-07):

'''
Class for opening and operating the PiSpy GUI
Copyright (C) 2022 Benjamin Morris, Marcy Kittredge, Bea Casey, Gregory Pask

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
You should have received a copy of the GNU General Public License
along with this program.  If not, see <https://www.gnu.org/licenses/>.
'''

from tkinter import *
from datetime import datetime
from Time_Lists import *
from Import_Trigger import *
from Image import *
from picamera import PiCamera
import sched
import time as t

class App:
    
    def __init__(self, master, title):
        self.master = master
        self.master.title(title)
        self.master.maxsize(2000, 20000)
        self.resolution = [1280, 720] #default resolution if none selected
        self.framerate = 0 #must be reset if video mode selected
        self._setUpDisplay()
        self._takeAction()
        super(Time_Lists).__init__()


        
    def _takeAction(self):

        def enable_video(): #function to check if video box is checked
            if video.get() %2 != 0:#if video box is checked, enable video setting control
                self.capture_box.config(state = NORMAL)
                self.framerate_box.config(state = NORMAL)
                if timedVideoMode.get() %2 != 0: #if timed video selected
                    self.frequency_box.config(state = NORMAL)
                if triggerVideoMode.get() %2 != 0: #if triggered video selected
                    self.input_trigger_box.config(state = NORMAL)
                    self.delay_box.config(state = NORMAL)
                self.duration_box.config(state = NORMAL)
            else: #otherwise, disable video setting controls
                self.capture_box.config(state = DISABLED)
                self.frequency_box.config(state = DISABLED)
                self.duration_box.config(state = DISABLED)
                self.input_trigger_box.config(state = DISABLED)
                self.delay_box.config(state = DISABLED)
                self.framerate_box.config(state = DISABLED)

        video = IntVar() #creates variable to enable video controls
        self.video_capture_mode = Checkbutton(self.master, text = "Video Capture Mode", variable=video, command=enable_video) #create video check box
        self.video_capture_mode.grid(row=0, column=0, sticky=W) #set location of video check box
        
        def enable_timed_video(): #checks if timed video selected and enables/disables boxes accordingly
            if timedVideoMode.get() %2 != 0 and video.get() %2 != 0:
                self.capture_box.config(state = NORMAL)
                self.frequency_box.config(state = NORMAL)
                self.duration_box.config(state = NORMAL)
            else:
                self.frequency_box.config(state = DISABLED)
        
        timedVideoMode = IntVar() #creates variable to enable timed video mode
        self.timed_video_capture_mode = Checkbutton(self.master, text = "Timed", variable=timedVideoMode, command=enable_timed_video) #create timed video check box
        self.timed_video_capture_mode.grid(row=4, column=0, sticky=W) #set location of timed video check box
        
        def enable_trigger_video(): #checks if triggered video selected and enables/disables boxes accordingly
            if triggerVideoMode.get() %2 != 0 and video.get() %2 != 0:
                self.capture_box.config(state = NORMAL)
                self.duration_box.config(state = NORMAL)
                self.input_trigger_box.config(state = NORMAL)
                self.delay_box.config(state = NORMAL)
            else:
                self.input_trigger_box.config(state = DISABLED)
                self.delay_box.config(state = DISABLED)
        
        triggerVideoMode = IntVar() #creates variable to enable triggered video mode
        self.trigger_video_capture_mode = Checkbutton(self.master, text = "Input Trigger", variable=triggerVideoMode, command=enable_trigger_video) #create input trigger video check box
        self.trigger_video_capture_mode.grid(row=6, column=0, sticky=W) #set location of triggered video check box
     
        def enable_image(): #function to check if image mode is selected
            if image.get() %2 != 0: #image is selected
                if timedImageMode.get() %2 != 0: #timed image is selected
                    self.i_frequency_box.config(state = NORMAL)
                if triggerImageMode.get() %2 != 0: #triggered image is selected
                    self.i_input_trigger_box.config(state = NORMAL)
                    self.i_delay_box.config(state = NORMAL)
                self.i_duration_box.config(state = NORMAL)
            else: #image is not selected
                self.i_frequency_box.config(state = DISABLED)
                self.i_duration_box.config(state = DISABLED)
                self.i_input_trigger_box.config(state = DISABLED)
                self.i_delay_box.config(state = DISABLED)
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

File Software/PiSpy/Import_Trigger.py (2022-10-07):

'''
Class for triggered recording of images or videos
Copyright (C) 2022 Benjamin Morris, Marcy Kittredge, Bea Casey, Gregory Pask

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
You should have received a copy of the GNU General Public License
along with this program.  If not, see <https://www.gnu.org/licenses/>.
'''

from Image import *
from Record import *
from Day_Night_Mode import *
import RPi.GPIO as GPIO
from datetime import datetime
from picamera import PiCamera

class Import_Trigger: #class for triggered recording
    
    def timed_delay(self, delay, RONTime, WONTime, ROFFTime, WOFFTime): #function used to check for lights on/off while delay is happening
        lights = Day_Night() #initiates lights class
        for x in range(delay): #every second for the length of the specified delay, checks if lights need to be switched then sleeps for 1 second 
            lights.light_on(RONTime, WONTime, ROFFTime, WOFFTime)
            sleep(1)
    
    def image_trigger(self, ID, delay, trigger, duration, RONTime, WONTime, ROFFTime, WOFFTime, resolution): #manages sensing and acquisition of images
        z = 0 #counter for how many images have been taken
        GPIO.setmode(GPIO.BCM) #set BCM GPIO numbering (how pins are referenced) 
        GPIO.setwarnings(False) # disables warnings
        GPIO.setup(trigger, GPIO.IN) # sets GPIO connected to sensor as an input 
        lights = Day_Night() #initiates lights class
        delay = int(delay[0:2])*60 + int(delay[3:5]) #calculates delay in seconds from input string in hh:mm format
        duration = int(duration * 60) #converts duration to minutes
        end_mins = int(datetime.now().strftime("%M")) + duration 
        end_hours = int(end_mins // 60) + int(datetime.now().strftime("%H")) #calculate hour of ending time
        end_mins = int(end_mins % 60) #calculates minutes of ending time (along with line 24
        days = 0
        while end_hours >= 24: #sets number of days during which recording will occur
            end_hours = end_hours - 24
            days += 1
        end_hours = str(end_hours) #recalculates hour of ending time after removing days
        if len(end_hours) == 1:
            end_hours = '0' + end_hours #reformats hours
        end_mins = str(end_mins)
        if len(end_mins) == 1:
            end_mins = '0' + end_mins #reformats minutes
        end_time = end_hours + end_mins #sets end time with correct formatting
        cam = PiCamera() #initates PiCamera. Recording is managed here to avoid camera needing to sleep after being triggered
        if GPIO.input(14) == 1:# if red light is on, use night settings
            lights.camNight(cam, resolution)
        else:# otherwise, use day settings
            lights.camDay(cam, resolution)
        while days >= 0:
            if datetime.now().strftime('%H%M') == end_time: #if reaches end time but there are still 1 or more days remaining, decrease days by 1 
                days = days - 1
                self.timed_delay(60, RONTime, WONTime, ROFFTime, WOFFTime) #delays for 1 minute to prevent loop from running again      
            i = GPIO.input(trigger)
            lights.light_on(RONTime, WONTime, ROFFTime, WOFFTime)
            x =0
            j = 0
            while j < 750: #remove this while loop if using motion sensor. For a break beam, the output is 0 when the beam is broken and 1 when it is not, but the output is not consistent when it should be 1. This loop creates a threshold to prevent accidental activation
                #print(i) #this line can be helpful to make sure the break beam is working correctly (if uncommented, output should be repeatedly printing 1 until break beam is triggered
                x = x + i
                j += 1
                i = GPIO.input(trigger)
            #print(GPIO.input(trigger))
            if x==0: #break beam is broken, for motion sensor switch to if i >= 1 (some sensors output a 1 when triggered and some output a 0, for other sensors test the output by uncommenting the above print statement to determine what to use
                print('capturing image')
                timestamp = datetime.now().strftime("%Y_%m_%d_%H_%M_%S") #sets variable for current time (to seconds)
                timestamp = ID + 'image' + str(z).zfill(5) + '_' + timestamp
                cam.capture("/home/pi/Pictures/{}.jpg".format(timestamp)) #takes image, saves to specified path with the timestamp as the format
                cam.close() #close camera
                self.timed_delay(delay, RONTime, WONTime, ROFFTime, WOFFTime) #delays specified amount of time, but still checks if lights need to be switched
                cam = PiCamera() #re-opens camera
                if GPIO.input(14) == 1:# if red light is on, use night settings
                    lights.camNight(cam, resolution)
                else:# otherwise, use day settings
                    lights.camDay(cam, resolution)
                z += 1
                print('ready to capture again')
        
    
    def video_trigger(self, ID, delay, trigger, duration, length, RONTime, WONTime, ROFFTime, WOFFTime, resolution, framerate): #manages sensing and acquisition of videos
        z = 0 #counter for how many videos have been recorded
        GPIO.setmode(GPIO.BCM) #set BCM GPIO numbering (how pins are referenced) 
        GPIO.setwarnings(False) # disables warnings
        GPIO.setup(trigger, GPIO.IN) # sets GPIO connected to sensor as an input 
        lights = Day_Night() #initiates lights class
        delay = int(delay[0:2])*60 + int(delay[3:5]) #calculates delay in seconds from input string in mm:ss format
        length = int(length[0:2])*60 + int(length[3:5]) #calculates video length in seconds from input string in mm:ss format
        duration = int(duration * 60) #converts duration to minutes
        end_mins = int(datetime.now().strftime("%M")) + duration
        end_hours = int(end_mins // 60) + int(datetime.now().strftime("%H")) #calculate hour of ending time
        end_mins = int(end_mins % 60)#calculates minutes of ending time (along with line 24
        days = 0
        while end_hours >= 24: #sets number of days during which recording will occur
            end_hours = end_hours - 24
            days += 1
        end_hours = str(end_hours) #recalculates hour of ending time after removing days
        if len(end_hours) == 1:
            end_hours = '0' + end_hours #reformats hours
        end_mins = str(end_mins)
        if len(end_mins) == 1:
            end_mins = '0' + end_mins #reformats minutes
        end_time = end_hours + end_mins #sets end time with correct formatting
        cam = PiCamera() #initates PiCamera. Recording is managed here to avoid camera needing to sleep after being triggered
        if GPIO.input(14) == 1: # if red light is on, use night settings
            lights.cam_night(cam, resolution, framerate)
        else: #otherwise, use day settings
            lights.cam_day(cam, resolution, framerate)
        while days >= 0:
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

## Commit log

2021-02-01 Rename camera.py to OOP v5/camera.py
2022-03-10 Laser Cutter and 3D printer files
    [Camera mount.stl, RPi mount.STL]
2022-03-21 A simple mount to attach to a lid or cover
    Mount holds Pi camera and LED PCB
    [Design1 - Board Outline.gbr, Design1 - Copper Bottom.gbr, Design1 - Copper Top-Copper Bottom.drl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]
2022-06-11 Update Laser Cut Wooden Stand.svg
2022-06-11 Update LED diffuser.svg
2022-06-11 Update antbox wooden stand 6mm.svg
2022-06-11 Update camera and LED board mount_laser cut.svg
2022-07-01 Updated with new assembly and install steps

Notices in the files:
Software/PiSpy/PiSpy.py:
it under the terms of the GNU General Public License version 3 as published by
